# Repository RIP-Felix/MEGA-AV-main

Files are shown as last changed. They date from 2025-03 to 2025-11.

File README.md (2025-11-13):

# MegaAV
Sega Genesis audio and video bypass, incorporating an entirely new audio circuit design that restores mono audio, along with native composite and S-video generation.

Attribution: Credit where Credit's due

Timeline of events:
ACE9921 & Villahed94 developed the original Mega Amp 1.0. Inception for a mod board that combines the Mega Amp with an RGB video amplifier was Bob from RetroRGB's idea. Rene from db Electronics designed the first build. Tienfeng designed the second with a modified version of the then new Mega Amp 2.0, on which Jose Cruz helped with testing. That became the Triple Bypass v2.

Zaxour forked the 3BPv2 to support Composite restore with the 3BPV2+ and is continuing development of a Quadruple Bypass that will support S-video.

For most of the 6 years between the Mega Amp 2.0 and 3.0, Ace was pretty much developing alone. Villahed94, eep386, and ACE9921 were throwing ideas around, but nobody except Ace was doing anything. I want to make it clear that the Mega Amp 3 is it's own standalone thing still in development and that the Mega Audio is NOT to be confused with it. Ace is not associated with the MegaAV.

While they may use similar circuit topology, their goals are different, and they must not be used interchangeably

RIP-Felix incepted the idea of restoring Mono Audio for RF compatibility. RGBeter incepted the idea of recreating Composite video using a modern encoder, taking the opportunity to fix the luma trap. At that point it was still a derivative work of the 3BPV2+. Villahed94 agreed to join the MegaAV team to finish and implement the Mega Audio for both inboard and MegaAV mod board installations. The three of us tested and refined finalized values, and implemented the designs together. Both RIP-Felix and RGBeter designed the MegaAV PCB. The only part of the circuit that has remained unchanged is the THS7374 RGB amplifier. 

So the Mega AV is actually 2 mods in one. The Mega Video developed by RIP-Felix, RGBeter, and Villahed94. Mega Audio was developed with help from Villahed94 and others along the way. Villahed94, RGBeter and RIP-Felix dialed in PSG and FM resistor values to dial in MD fourier. That said I (RIP-Felix) want to thank and credit everyone involved in these mods regardless of how much of their contributions made it into the current version of Mega AV. It's been a collective effort and everyone should be credited for the hard work they've put in! Massive thanks to all of you!
 
NOTEs:
- Fujitsu ASICs, 315-5708-01 and 315-5660-01 needed an additional pulldown resistor. Instead of bridging jumper C, solder a 200Ohm 1% or lower tolerance resistor to it. May apply to Model 1 VA7 through Model 2 VA1.8. The Suffix -01 indicates it's a Fujitsu Chip. This DOES NOT apply to chips LACKING the suffix "-01".
- Adds a ZIF connector for a future ribbon cable design to greatly simplify installation

(instructions pending, same as 3bp install except composite and mono must also be isolated from the din, and the subcarrier line must be routed to the MegaAV)
### When routing the subcarrier line, make sure it's a shielded coaxial cable or twisted pair to prevent jailbars

Instructions pending:
## Model 1 Installation Guides
[Model 1 - VA1-VA6]
[Model 1 - VA7]
## Model 2 Installation Guides
[Model 2 - VA0-1.8]
[Model 2 - VA2]
[Model 2 - VA2.3] (needed)
[Model 2 - VA3]
[Model 2 - VA4]

## Model 3 Installation Guides
[Model 3 - VA1] (needed)
[Model 3 - VA2] (needed)

## Sega CDX
[CDX]

## Other
[Other forms of Genesis]

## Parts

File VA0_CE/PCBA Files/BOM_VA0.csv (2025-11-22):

R15,R17,R74,R75,R76 | 75 | Resistor_SMD:R_0402_1005Metric | C4275
R60,R61 | 100 | Resistor_SMD:R_0402_1005Metric | C25076
R53,R54,R55 | 330 | Resistor_SMD:R_0402_1005Metric | C25104
R34 | 820 | Resistor_SMD:R_0402_1005Metric | C23253
C32,C33,C39,C53 | 0.1uF | Capacitor_SMD:C_0805_2012Metric | C28233
R69,R71,R73 | 1.2k | Resistor_SMD:R_0402_1005Metric | C22765
C41,C45 | 100u | Capacitor_Tantalum_SMD:CP_EIA-3528-15_AVX-H | C16133
L1 | 100uH | Inductor_SMD:L_0805_2012Metric | C68035
R40,R41,R46,R47,R48,R49,R62,R64 | 10k | Resistor_SMD:R_0402_1005Metric | C25744
C3,C4,C14,C15,C19,C20,C21,C22,C24,C25,C26,C27,C28,C29,C30,C31,C34,C37,C51,C52,C54,C55 | 10uF | Capacitor_SMD:C_0805_2012Metric | C15850
C50 | 12p | Capacitor_SMD:C_0402_1005Metric | C1547
R30 | 15k | Resistor_SMD:R_0402_1005Metric | C25756
R70 | 1k | Resistor_SMD:R_0402_1005Metric | C11702
D2 | 1N4148W | Diode_SMD:D_SOD-323 | C2128
R21,R23,R36,R67,R68 | 2.2k | Resistor_SMD:R_0402_1005Metric | C25879
U2 | 2.5v linear Regulator | Package_TO_SOT_SMD:TSOT-23-5 | C22466441
R35 | 20k | Resistor_SMD:R_0402_1005Metric | C25765
C46,C47,C48,C56 | 220uF | Capacitor_Tantalum_SMD:CP_EIA-3528-15_AVX-H | C122649
R22,R24,R25 | 22k | Resistor_SMD:R_0402_1005Metric | C25768
R33 | 3.6k | Resistor_SMD:R_0402_1005Metric | C22980
R26,R29 | 36k | Resistor_SMD:R_0402_1005Metric | C23147
R52,R57,R58,R66 | 4.7k | Resistor_SMD:R_0402_1005Metric | C25900
R4,R5,R7,R8,R31,R32,R59,R72 | 47k | Resistor_SMD:R_0402_1005Metric | C25792
C1,C9,C11,C12,C13 | 47p | Capacitor_SMD:C_0402_1005Metric | C1567
C42,C43,C44 | 47u | Capacitor_SMD:C_1206_3216Metric | C96123
R37,R38,R56 | 5.6k | Resistor_SMD:R_0402_1005Metric | C23189
C35,C36 | 5.6nF | Capacitor_SMD:C_0402_1005Metric | C2976066
R27,R28,R65,R79 | 51k | Resistor_SMD:R_0402_1005Metric | C25794
C38 | 5p | Capacitor_SMD:C_0805_2012Metric | C309040
R39,R42 | 7.5k | Resistor_SMD:R_0402_1005Metric | C23234
C49 | 7p | Capacitor_SMD:C_0402_1005Metric | C5448838
R45 | 82k | Resistor_SMD:R_0402_1005Metric | C23254
Designator | Comment | Footprint | JLCPCB Part #
Z1 | Conn_01x33_Pin | Connector_FFC-FPC:Molex_502244-3330_1x33-1MP_P0.5mm_Horizontal
U6 | TS922 | Package_SO:SO-8_3.9x4.9mm_P1.27mm | C93687
U3 | TS924 | Package_SO:SO-14_3.9x8.65mm_P1.27mm | C1235674
U7 | TS924 | Package_SO:SO-14_3.9x8.65mm_P1.27mm | C1235674

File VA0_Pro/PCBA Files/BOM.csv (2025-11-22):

Designator | Comment | Footprint | LCSC Part #
R15,R17,R36,R37,R38,R43,R44,R45,R56,R57,R58 | 75 | Resistor_SMD:R_0603_1608Metric | C4275
R60,R61,R66,R67 | 100 | Resistor_SMD:R_0402_1005Metric | C25076
R53,R54,R55 | 330 | Resistor_SMD:R_0402_1005Metric | C25104
R69,R70,R71 | 374 | Resistor_SMD:R_0402_1005Metric | C270604
R68 | 620 | Resistor_SMD:R_0402_1005Metric | C4961
R34 | 820 | Resistor_SMD:R_0603_1608Metric | C23253
C23 | 0.01u | Capacitor_SMD:C_0402_1005Metric | C15195
C2,C8,C28,C30,C31,C32,C33,C34,C37,C39 | 100n | Capacitor_SMD:C_0402_1005Metric | C28233
C16,C17,C18 | 0.1u | Capacitor_SMD:C_0402_1005Metric | C1525
L1 | 100uH | Inductor_SMD:L_0805_2012Metric | C68035
R2,R3,R20,R40,R41,R46,R47,R48,R49,R62,R64 | 10k | Resistor_SMD:R_0402_1005Metric | C25744
C1,C3,C4,C10,C14,C15,C19,C20,C21,C22,C24,C25,C26,C27,C29,C38,C54,C55 | 10u | Capacitor_SMD:C_0805_2012Metric | C15850
C50 | 12p | Capacitor_SMD:C_0402_1005Metric | C1547
R30 | 15k | Resistor_SMD:R_0402_1005Metric | C25756
R16,R18,R19 | 1k | Resistor_SMD:R_0402_1005Metric | C11702
C6 | 1n | Capacitor_SMD:C_0402_1005Metric | C1523
D1,D2 | 1N4148W | Diode_SMD:D_SOD-323 | C2128
R6,R21,R23 | 2.2k | Resistor_SMD:R_0402_1005Metric | C25879
C41,C45,C46,C47,C48,C56 | 220u | Capacitor_Tantalum_SMD:CP_EIA-3528-15_AVX-H | C122649
R22,R24,R25 | 22k | Resistor_SMD:R_0402_1005Metric | C25768
C5,C7 | 22n | Capacitor_SMD:C_0402_1005Metric | C1532
R33 | 3.6k | Resistor_SMD:R_0603_1608Metric | C22980
R26,R29 | 36k | Resistor_SMD:R_0603_1608Metric | C23147
R1,R52 | 4.7k | Resistor_SMD:R_0402_1005Metric | C25900
R4,R5,R7,R8,R31,R32,R59,R72 | 47k | Resistor_SMD:R_0402_1005Metric | C25792
C9,C11,C12,C13 | 47p | Capacitor_SMD:C_0402_1005Metric | C1567
C42,C43,C44 | 47u | Capacitor_SMD:C_1206_3216Metric | C96123
R9,R10,R11,R12,R13,R14,R35 | 5.6k | Resistor_SMD:R_0603_1608Metric | C23189
R27,R28,R63,R65 | 51k | Resistor_SMD:R_0402_1005Metric | C25794
C35,C36 | 5600p | Capacitor_SMD:C_0402_1005Metric | C2976066
R39,R42 | 7.5k | Resistor_SMD:R_0603_1608Metric | C23234
U2 | 74HCT123 | Package_SO:TSSOP-16_4.4x5mm_P0.65mm | C191980
C49 | 7p | Capacitor_SMD:C_0402_1005Metric | C5448838
U8 | AD723 | Package_SO:TSSOP-28_6.1x9.7mm_P0.65mm
U1 | CD4070 | Package_SO:TSSOP-14_4.4x5mm_P0.65mm | C2865674
Z1 | Conn_01x33_Pin | Connector_FFC-FPC:Molex_502244-3330_1x33-1MP_P0.5mm_Horizontal
U5 | ICS501 | Package_SO:SOIC-8_3.9x4.9mm_P1.27mm
CN1 | MD-90SM_MD2 | MyLibrary:MD90SM-MD2
U9 | 2.5v linear Regulator | Package_TO_SOT_SMD:TSOT-23-5 | C22466441
U4 | THS7374 | Package_SO:TSSOP-14_4.4x5mm_P0.65mm
U6 | TS922 | Package_SO:TSSOP-8_4.4x3mm_P0.65mm | C93687
U3,U7 | TS924 | Package_SO:TSSOP-14_4.4x5mm_P0.65mm

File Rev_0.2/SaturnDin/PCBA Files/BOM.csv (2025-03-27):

Designator | Comment | Footprint
~ | 5V1,32XPD1,32XPD2,B_IN1,CDPD1,CDPD2,CLK_IN1,GND1,G_IN1,LPF1,M1PU1,PAL1,R_IN1,S_IN1 | Connector_Wire:SolderWirePad_1x01_SMD_1x2mm,Jumper:SolderJumper-2_P1.3mm_Open_RoundedPad1.0x1.5mm
SMD_Conn_01x01 | 32X_L1,32X_R1,CD_L1,CD_R1,FM_L1,FM_R1,P1 | Connector_Wire:SolderWirePad_1x01_SMD_1x2mm
0.01u | C1 | Capacitor_SMD:C_0402_1005Metric
10u | C2,C3,C8,C9,C14,C15,C16,C17,C19,C20,C21,C22,C23,C32,C45,C48 | Capacitor_SMD:C_0805_2012Metric
27p | C4,C5,C6,C7 | Capacitor_SMD:C_0402_1005Metric
0.1u | C10,C11,C12,C13,C18,C27,C28,C29,C33,C46,C47 | Capacitor_SMD:C_0402_1005Metric
220u | C24,C25,C26,C36,C38,C41,C42,C43,C44 | Capacitor_Tantalum_SMD:CP_EIA-3528-15_AVX-H
5600p | C30,C31 | Capacitor_SMD:C_0402_1005Metric
47u | C34,C35 | Capacitor_Tantalum_SMD:CP_EIA-3528-15_AVX-H
9p | C39 | Capacitor_SMD:C_0402_1005Metric
18p | C40 | Capacitor_SMD:C_0402_1005Metric
MD-90SM_MD2 | CN1 | MyLibrary:MD10SM-SS
1N4148W | D1 | Diode_SMD:D_SOD-123
SolderJumper_2_Open | FM_L1-1,FM_L1-2,FM_L2-1,FM_L2-2,FM_L3-1,FM_L3-2,FM_R1-1,FM_R1-2,FM_R2-1,FM_R2-2,FM_R3-1,FM_R3-2 | Jumper:SolderJumper-2_P1.3mm_Open_RoundedPad1.0x1.5mm
SolderJumper_3_Open | PSGPD1 | Jumper:SolderJumper-3_P1.3mm_Open_RoundedPad1.0x1.5mm
100k | R1,R2,R3,R4,R20,R23,R48,R49 | Resistor_SMD:R_0402_1005Metric
2.2k | R5,R8 | Resistor_SMD:R_0402_1005Metric
5.62k | R6,R9,R10,R11,R12,R13,R16,R32,R42 | Resistor_SMD:R_0402_1005Metric
750 | R7 | Resistor_SMD:R_0402_1005Metric
1k | R14,R15,R17 | Resistor_SMD:R_0402_1005Metric
75 | R18,R25,R33,R34,R35,R36,R37,R43,R44,R46,R52,R54,R56,R57,R58,R59 | Resistor_SMD:R_0402_1005Metric
10k | R19,R22,R61,R62 | Resistor_SMD:R_0402_1005Metric
130k | R21,R24 | Resistor_SMD:R_0402_1005Metric
210k | R26,R27,R28,R29 | Resistor_SMD:R_0402_1005Metric
300k | R30,R31 | Resistor_SMD:R_0402_1005Metric
21k | R38,R41 | Resistor_SMD:R_0402_1005Metric
30k | R39,R40,R45,R47 | Resistor_SMD:R_0402_1005Metric
330 | R50,R51 | Resistor_SMD:R_0402_1005Metric
51k | R53 | Resistor_SMD:R_0402_1005Metric
470 | R60 | Resistor_SMD:R_0402_1005Metric
ICS501 | U1 | Package_SO:SOIC-8_3.9x4.9mm_P1.27mm
MC33204 | U2,U4 | Package_SO:TSSOP-14_4.4x5mm_P0.65mm
THS7374 | U3 | Package_SO:TSSOP-14_4.4x5mm_P0.65mm
AD725 | U5 | Package_SO:SOIC-16W_7.5x10.3mm_P1.27mm
Conn_01x33_Pin | Z1 | Connector_FFC-FPC:Molex_502244-3330_1x33-1MP_P0.5mm_Horizontal

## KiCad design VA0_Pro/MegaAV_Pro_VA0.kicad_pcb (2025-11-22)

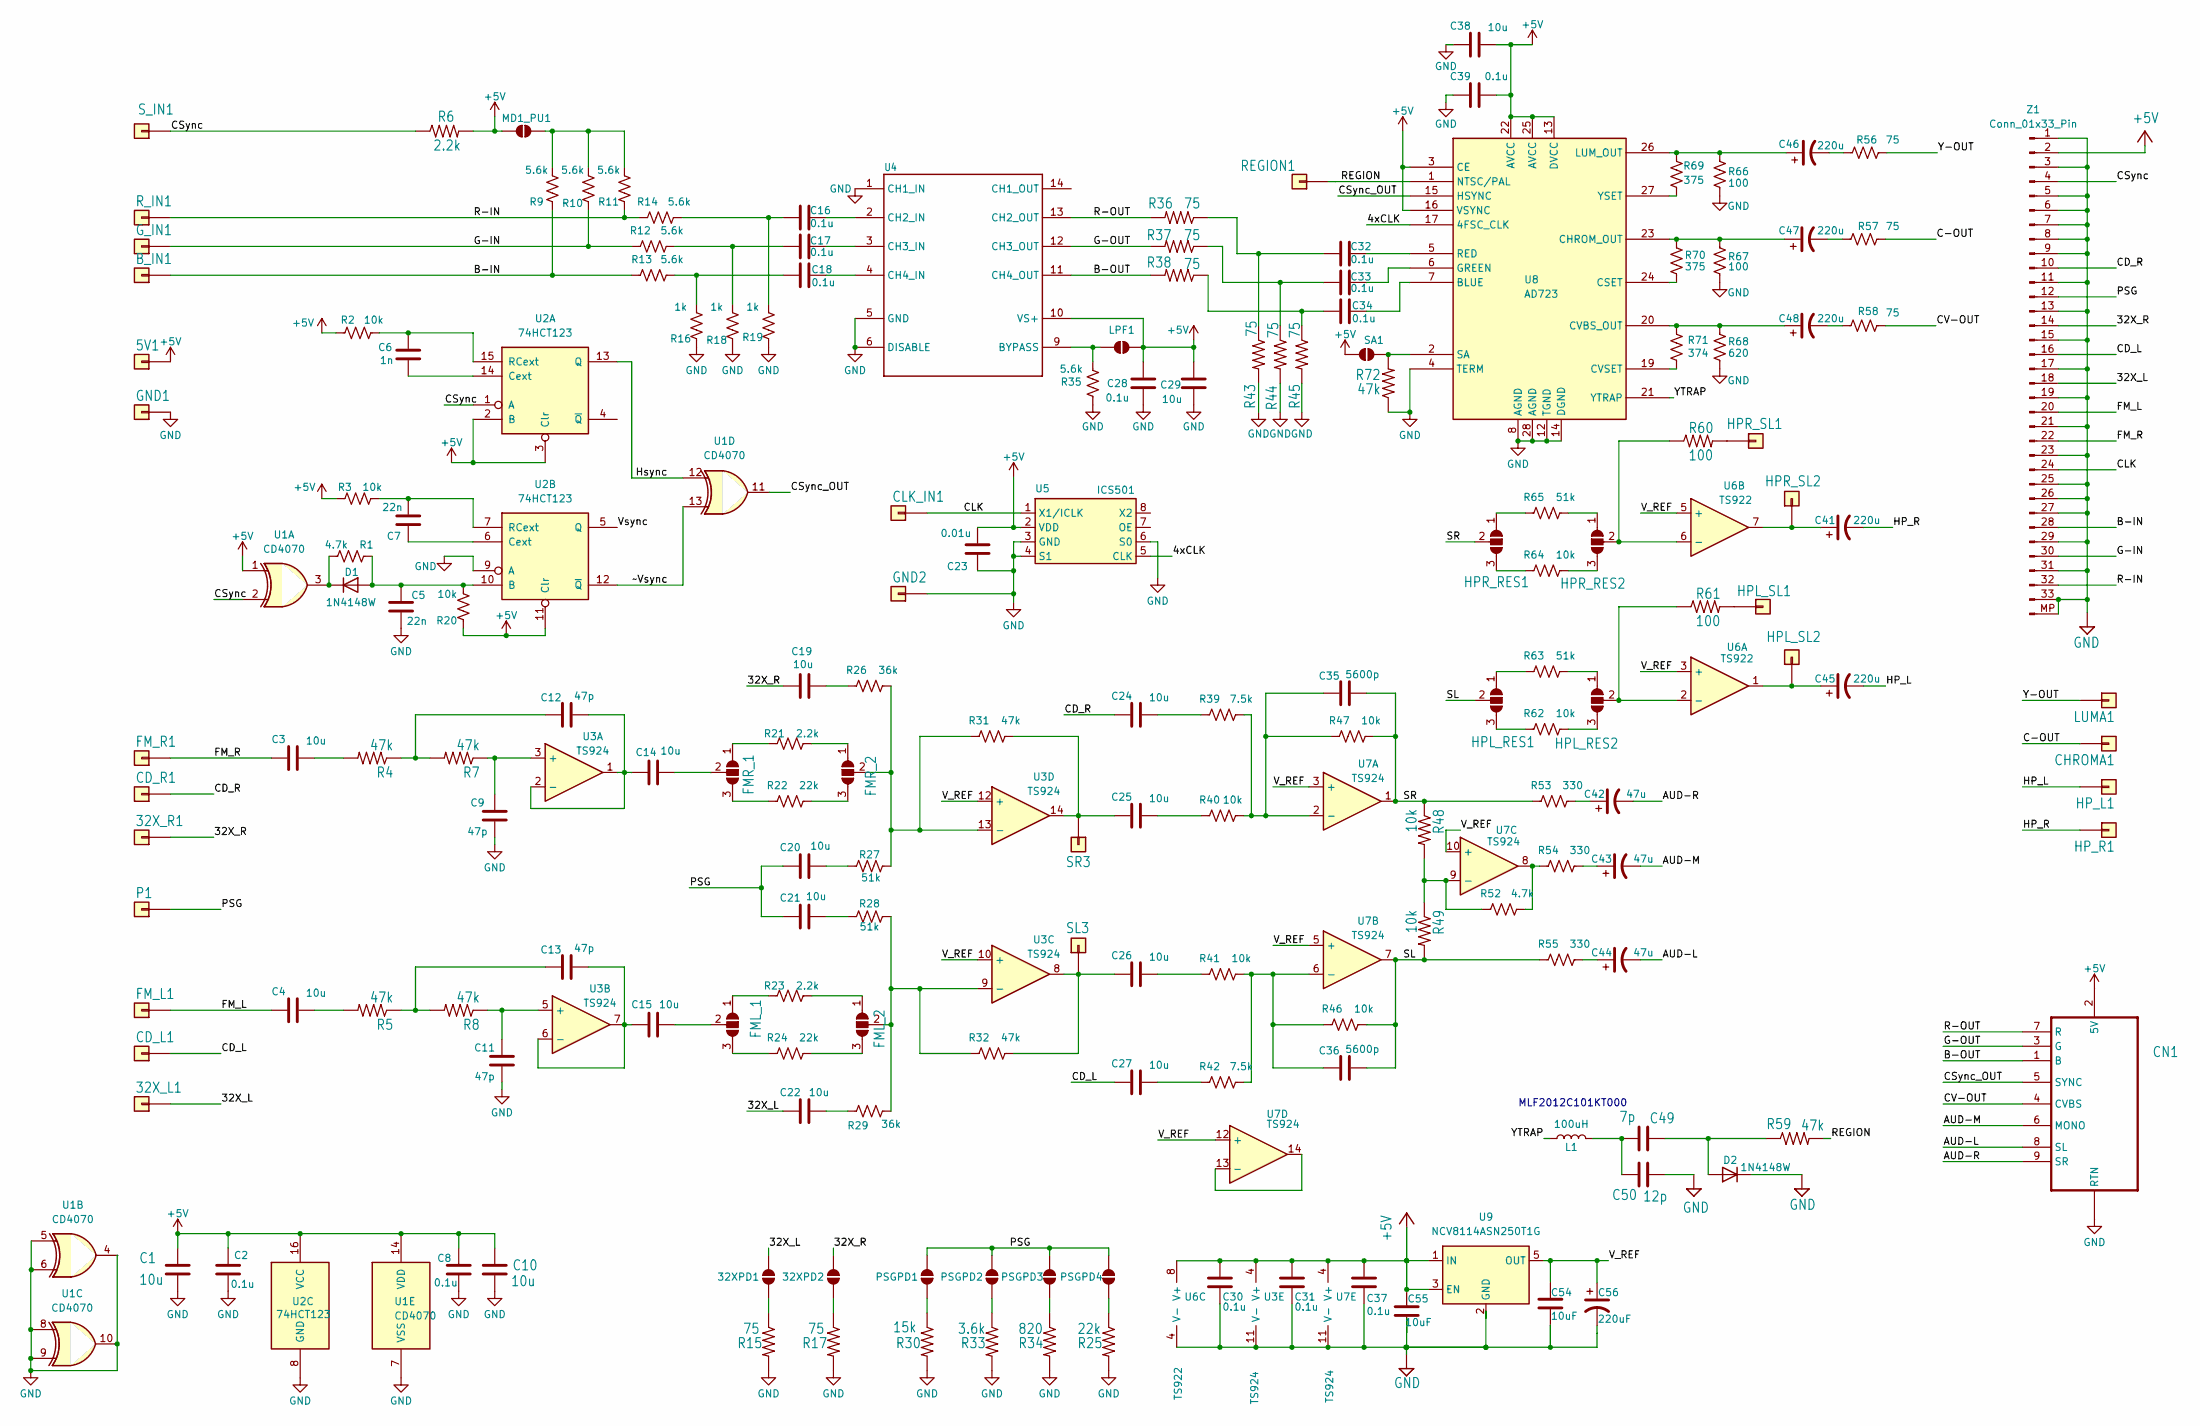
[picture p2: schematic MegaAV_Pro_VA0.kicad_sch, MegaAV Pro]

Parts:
5V1: SolderWirePad_1x01_SMD_1x2mm
32XPD1, 32XPD2: SolderJumper-2_P1.3mm_Open_RoundedPad1.0x1.5mm
32X_L1, 32X_R1: SMD_Conn_01x01; SolderWirePad_1x01_SMD_1x2mm
B_IN1: SolderWirePad_1x01_SMD_1x2mm
C1, C3, C4, C10, C14, C15, C19, C20, C21, C22, C24, C25, C26, C27, C29, C38: 10u; C_0805_2012Metric
C2, C8, C16, C17, C18, C30, C31, C32, C33, C34, C37, C39: 0.1u; C_0402_1005Metric
C5, C7: 22n; C_0402_1005Metric
C6: 1n; C_0402_1005Metric
C9, C11, C12, C13: 47p; C_0402_1005Metric
C23: 0.01u; C_0402_1005Metric
C28: 0.1u; C_0805_2012Metric
C35, C36: 5600p; C_0402_1005Metric
C41, C45, C46, C47, C48: 220u; CP_EIA-3528-15_AVX-H
C42, C43, C44: 47u; C_1206_3216Metric
C49: 7p; C_0402_1005Metric
C50: 12p; C_0402_1005Metric
C54: 10uF; C_0805_2012Metric; MPN VJ0805A330FXJPW1BC; LCSC Part # C520060
C55: 10uF; C_0805_2012Metric
C56: 220uF; CP_EIA-3528-15_AVX-H
CD_L1: SMD_Conn_01x01; SolderWirePad_1x01_SMD_1x2mm
CD_R1: SMD_Conn_01x01; SolderWirePad_1x01_SMD_1x2mm
CHROMA1: SMD_Conn_01x01; SolderWirePad_1x01_SMD_1x2mm
CLK_IN1: SolderWirePad_1x01_SMD_1x2mm
CN1: MD-90SM_MD2; MD90SM-MD2
D1, D2: 1N4148W; D_SOD-323F
FML_1, FML_2: SolderJumper_3_Open; SolderJumper-3_P1.3mm_Open_RoundedPad1.0x1.5mm
FMR_1, FMR_2: SolderJumper_3_Open; SolderJumper-3_P1.3mm_Open_RoundedPad1.0x1.5mm
FM_L1: SMD_Conn_01x01; SolderWirePad_1x01_SMD_1x2mm
FM_R1: SMD_Conn_01x01; SolderWirePad_1x01_SMD_1x2mm
GND1: SolderWirePad_1x01_SMD_1x2mm
GND2: SMD_Conn_01x01; SolderWirePad_1x01_SMD_1x2mm
G_IN1: SolderWirePad_1x01_SMD_1x2mm
HPL_RES1, HPL_RES2: SolderJumper_3_Open; SolderJumper-3_P1.3mm_Open_RoundedPad1.0x1.5mm
HPL_SL1, HPL_SL2: SMD_Conn_01x01; SolderWirePad_1x01_SMD_1x2mm
HPR_RES1, HPR_RES2: SolderJumper_3_Open; SolderJumper-3_P1.3mm_Open_RoundedPad1.0x1.5mm
HPR_SL1, HPR_SL2: SMD_Conn_01x01; SolderWirePad_1x01_SMD_1x2mm
HP_L1: SMD_Conn_01x01; SolderWirePad_1x01_SMD_1x2mm
HP_R1: SMD_Conn_01x01; SolderWirePad_1x01_SMD_1x2mm
L1: 100uH; L_0805_2012Metric
LPF1: SolderJumper-2_P1.3mm_Open_RoundedPad1.0x1.5mm
LUMA1: SMD_Conn_01x01; SolderWirePad_1x01_SMD_1x2mm
MD1_PU1: SolderJumper-2_P1.3mm_Open_RoundedPad1.0x1.5mm
P1: SMD_Conn_01x01; SolderWirePad_1x01_SMD_1x2mm
PSGPD1, PSGPD2, PSGPD3, PSGPD4: SolderJumper-2_P1.3mm_Open_RoundedPad1.0x1.5mm
R1, R52: 4.7k; R_0402_1005Metric
R2, R3, R20, R40, R41, R46, R47, R48, R49, R62, R64: 10k; R_0402_1005Metric
R4, R5, R7, R8, R31, R32, R59, R72: 47k; R_0402_1005Metric
R6, R21, R23: 2.2k; R_0402_1005Metric
R9, R10, R11, R12, R13, R14, R35: 5.6k; R_0603_1608Metric
R15, R17, R36, R37, R38, R43, R44, R45, R56, R57, R58: 75; R_0603_1608Metric
R16, R18, R19: 1k; R_0402_1005Metric
R22, R24, R25: 22k; R_0402_1005Metric
R26, R29: 36k; R_0603_1608Metric
R27, R28, R63, R65: 51k; R_0402_1005Metric
R30: 15k; R_0402_1005Metric
R33: 3.6k; R_0603_1608Metric
R34: 820; R_0603_1608Metric
R39, R42: 7.5k; R_0603_1608Metric
R53, R54, R55: 330; R_0402_1005Metric
R60, R61, R66, R67: 100; R_0402_1005Metric
R68: 620; R_0402_1005Metric
R69, R70: 375; R_0402_1005Metric
R71: 374; R_0402_1005Metric
REGION1: SolderWirePad_1x01_SMD_1x2mm
R_IN1: SolderWirePad_1x01_SMD_1x2mm
SA1: SolderJumper-2_P1.3mm_Open_RoundedPad1.0x1.5mm
SL3: SMD_Conn_01x01; SolderWirePad_1x01_SMD_1x2mm
SR3: SMD_Conn_01x01; SolderWirePad_1x01_SMD_1x2mm
S_IN1: SolderWirePad_1x01_SMD_1x2mm
U1: CD4070; TSSOP-14_4.4x5mm_P0.65mm
U2: 74HCT123; TSSOP-16_4.4x5mm_P0.65mm
U3, U7: TS924; TSSOP-14_4.4x5mm_P0.65mm
U4: THS7374; TSSOP-14_4.4x5mm_P0.65mm
U5: ICS501; SOIC-8_3.9x4.9mm_P1.27mm
U6: TS922; SO-8_3.9x4.9mm_P1.27mm
U8: AD723; TSSOP-28_6.1x9.7mm_P0.65mm
U9: NCV8114ASN250T1G; TSOT-23-5
Z1: Conn_01x33_Pin; Molex_502244-3330_1x33-1MP_P0.5mm_Horizontal

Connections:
+5V: 5V1.1, C1.1, C2.1, C8.1, C10.1, C23.2, C28.1, C29.1, C30.1, C31.1, C37.1, C38.2, C39.2, C55.1, CN1.2 (5V), LPF1.2 (B), MD1_PU1.2 (B), R2.2, R3.1, R6.2, R20.1, SA1.1 (A), U1.1, U1.14 (VDD), U2.2 (B), U2.3 (Clr), U2.11 (Clr), U2.16 (VCC), U3.4 (V+), U4.10 (VS+), U5.2 (VDD), U6.8 (V+), U7.4 (V+), U8.3 (CE), U8.13 (DVCC), U8.16 (VSYNC), U8.22 (AVCC), U8.25 (AVCC), U9.1 (IN), U9.3 (EN), Z1.2
/4xCLK: U5.5 (CLK), U8.17 (4FSC_CLK)
/32X_L: 32XPD1.2 (B), 32X_L1.1, C22.1, Z1.18
/32X_R: 32XPD2.2 (B), 32X_R1.1, C19.1, Z1.14
/AUD-L: C44.2, CN1.8 (SL)
/AUD-M: C43.2, CN1.6 (MONO)
/AUD-R: C42.2, CN1.9 (SR)
/B-IN: B_IN1.1, R9.1, R13.1, Z1.28
/B-OUT: CN1.1 (B), R38.2, U4.11 (CH4_OUT)
/C-OUT: CHROMA1.1, R57.2
/CD_L: C27.1, CD_L1.1, Z1.16
/CD_R: C24.1, CD_R1.1, Z1.10
/CLK: CLK_IN1.1, U5.1 (X1/ICLK), Z1.24
/CSync: R6.1, S_IN1.1, U1.2, U2.1 (A), Z1.4
/CSync_OUT: CN1.5 (SYNC), U1.11, U8.15 (HSYNC)
/CV-OUT: CN1.4 (CVBS), R58.2
/FM_L: C4.1, FM_L1.1, Z1.20
/FM_R: C3.1, FM_R1.1, Z1.22
/G-IN: G_IN1.1, R10.1, R12.1, Z1.30
/G-OUT: CN1.3 (G), R37.2, U4.12 (CH3_OUT)
/HP_L: C45.2, HP_L1.1
/HP_R: C41.2, HP_R1.1
/Hsync: U1.12, U2.13 (Q)
/PSG: C20.1, C21.1, P1.1, PSGPD1.2 (B), PSGPD2.2 (B), PSGPD3.2 (B), PSGPD4.2 (B), Z1.12
/R-IN: R11.1, R14.1, R_IN1.1, Z1.32
/R-OUT: CN1.7 (R), R36.2, U4.13 (CH2_OUT)
/REGION: R59.2, REGION1.1, U8.1 (NTSC/PAL); also elsewhere on the board
/SL: C36.2, HPL_RES1.2 (C), R46.2, R49.2, R55.1, U7.7
/SR: C35.2, HPR_RES1.2 (C), R47.2, R48.1, R53.1, U7.1
/V_REF: C54.1, C56.1, U3.10 (+), U3.12 (+), U6.3 (+), U6.5 (+), U7.3 (+), U7.5 (+), U7.10 (+), U7.12 (+), U9.5 (OUT)
/Vsync: U2.5 (Q)
/Y-OUT: LUMA1.1, R56.2
/YTRAP: L1.1, U8.21 (YTRAP)
/~Vsync: U1.13, U2.12 (~Q)
GND: C1.2, C2.2, C5.1, C8.2, C9.2, C10.2, C11.2, C23.1, C28.2, C29.2, C30.2, C31.2, C37.2, C38.1, C39.1, C50.2, C54.2, C55.2, C56.2, CN1.S1 (RTN), CN1.S2 (RTN), CN1.S3 (RTN), D2.1 (K), GND1.1, GND2.1, R15.2, R16.1, R17.2, R18.1, R19.1, R25.2, R30.2, R33.2, R34.2, R35.1, R43.2, R44.2, R45.2, R66.2, R67.2, R68.2, R72.1, U1.4, U1.5, U1.6, U1.7 (VSS), U1.8, U1.9, U1.10, U2.8 (GND), U2.9 (A), U3.11 (V-), U4.1 (CH1_IN), U4.5 (GND), U4.6 (DISABLE), U5.3 (GND), U5.4 (S1), U5.6 (S0), U6.4 (V-), U7.11 (V-), U8.4 (TERM), U8.8 (AGND), U8.12 (TGND), U8.14 (DGND), U8.28 (AGND), U9.2 (GND), Z1.1, Z1.3, Z1.5, Z1.6, Z1.7, Z1.8, Z1.9, Z1.11, Z1.13, Z1.15, Z1.17, Z1.19, Z1.21, Z1.23, Z1.25, Z1.26, Z1.27, Z1.29, Z1.31, Z1.33, Z1.MP
unnamed: 32XPD1.1 (A), R15.1
unnamed: 32XPD2.1 (A), R17.1
unnamed: C3.2, R4.2
unnamed: C4.2, R5.2
unnamed: C12.1, R4.1, R7.2
unnamed: C13.1, R5.1, R8.2
unnamed: C16.1, R14.2, R19.2
unnamed: C17.1, R12.2, R18.2
unnamed: C18.1, R13.2, R16.2
unnamed: C19.2, R26.1
unnamed: C20.2, R27.1
unnamed: C21.2, R28.1
unnamed: C22.2, R29.1
unnamed: C24.2, R39.1
unnamed: C25.2, R40.1
unnamed: C26.2, R41.1
unnamed: C27.2, R42.1
unnamed: C32.1, R36.1, R43.1
unnamed: C33.1, R37.1, R44.1
unnamed: C34.1, R38.1, R45.1
unnamed: C42.1, R53.2
unnamed: C43.1, R54.2
unnamed: C44.1, R55.2
unnamed: C46.2, R56.1
unnamed: C47.2, R57.1
unnamed: C48.2, R58.1
unnamed: C49.2, C50.1, L1.2
unnamed: C5.2, D1.2 (A), R1.1, R20.2, U2.10 (B)
unnamed: D1.1 (K), R1.2, U1.3
unnamed: C49.1, D2.2 (A), R59.1
unnamed: FML_1.1 (A), R23.1
unnamed: FML_1.3 (B), R24.1
unnamed: C15.2, FML_1.2 (C)
unnamed: FML_2.1 (A), R23.2
unnamed: FML_2.3 (B), R24.2
unnamed: FML_2.2 (C), R28.2, R29.2, R32.1, U3.9 (-)
unnamed: FMR_1.1 (A), R21.1
unnamed: FMR_1.3 (B), R22.1
unnamed: C14.2, FMR_1.2 (C)
unnamed: FMR_2.1 (A), R21.2
unnamed: FMR_2.3 (B), R22.2
unnamed: FMR_2.2 (C), R26.2, R27.2, R31.1, U3.13 (-)
unnamed: HPL_RES1.1 (A), R63.1
unnamed: HPL_RES1.3 (B), R62.1
unnamed: HPL_RES2.1 (A), R63.2
unnamed: HPL_RES2.3 (B), R62.2
unnamed: HPL_RES2.2 (C), R61.1, U6.2 (-)
unnamed: HPL_SL1.1, R61.2
unnamed: C45.1, HPL_SL2.1, U6.1
unnamed: HPR_RES1.1 (A), R65.1
unnamed: HPR_RES1.3 (B), R64.1
unnamed: HPR_RES2.1 (A), R65.2
unnamed: HPR_RES2.3 (B), R64.2
unnamed: HPR_RES2.2 (C), R60.1, U6.6 (-)
unnamed: HPR_SL1.1, R60.2
unnamed: C41.1, HPR_SL2.1, U6.7
unnamed: LPF1.1 (A), R35.2, U4.9 (BYPASS)
unnamed: MD1_PU1.1 (A), R9.2, R10.2, R11.2
unnamed: PSGPD1.1 (A), R30.1
unnamed: PSGPD2.1 (A), R33.1
unnamed: PSGPD3.1 (A), R34.1
unnamed: PSGPD4.1 (A), R25.1
unnamed: R52.2, R54.1, U7.8
unnamed: R72.2, SA1.2 (B), U8.2 (SA)
unnamed: C26.1, R32.2, SL3.1, U3.8
unnamed: C25.1, R31.2, SR3.1, U3.14
unnamed: C6.1, U2.14 (Cext)
unnamed: C6.2, R2.1, U2.15 (RCext)
unnamed: C7.1, U2.6 (Cext)
unnamed: C7.2, R3.2, U2.7 (RCext)
unnamed: C9.1, R7.1, U3.3 (+)
unnamed: C12.2, C14.1, U3.1, U3.2 (-)
unnamed: C11.1, R8.1, U3.5 (+)
unnamed: C13.2, C15.1, U3.6 (-), U3.7
unnamed: C16.2, U4.2 (CH2_IN)
unnamed: C17.2, U4.3 (CH3_IN)
unnamed: C18.2, U4.4 (CH4_IN)
unnamed: C35.1, R39.2, R40.2, R47.1, U7.2 (-)
unnamed: C36.1, R41.2, R42.2, R46.1, U7.6 (-)
unnamed: R48.2, R49.1, R52.1, U7.9 (-)
unnamed: U7.13 (-), U7.14
unnamed: C34.2, U8.7 (BLUE)
unnamed: C47.1, R67.1, R70.2, U8.23 (CHROM_OUT)
unnamed: R70.1, U8.24 (CSET)
unnamed: C48.1, R68.1, R71.2, U8.20 (CVBS_OUT)
unnamed: R71.1, U8.19 (CVSET)
unnamed: C33.2, U8.6 (GREEN)
unnamed: C46.1, R66.1, R69.1, U8.26 (LUM_OUT)
unnamed: C32.2, U8.5 (RED)
unnamed: R69.2, U8.27 (YSET)

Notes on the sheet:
MLF2012C101KT000

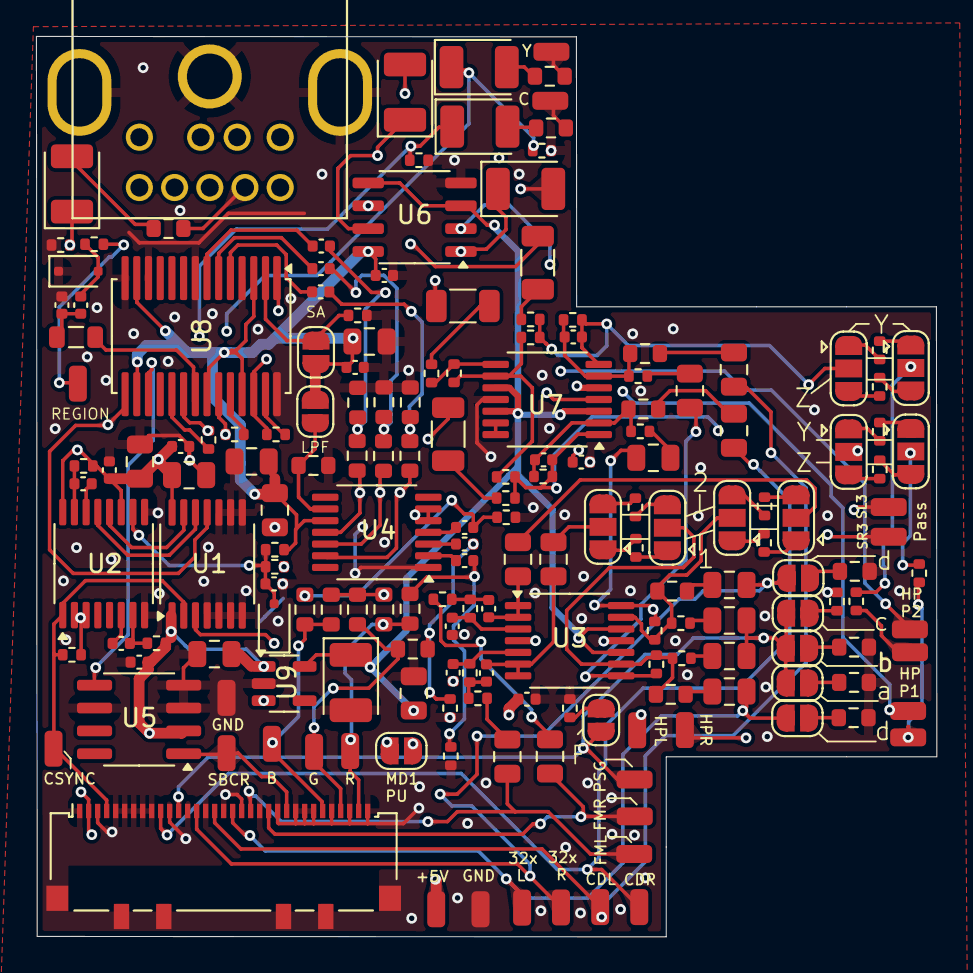
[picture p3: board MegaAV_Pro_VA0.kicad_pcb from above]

Board: 4 copper layers, 50.0 x 50.0 mm, 179 parts (0 on the bottom side), 124 nets.

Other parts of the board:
REGION: SolderWirePad_1x01_SMD_1x2mm

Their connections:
/REGION: REGION.1; also elsewhere on the board

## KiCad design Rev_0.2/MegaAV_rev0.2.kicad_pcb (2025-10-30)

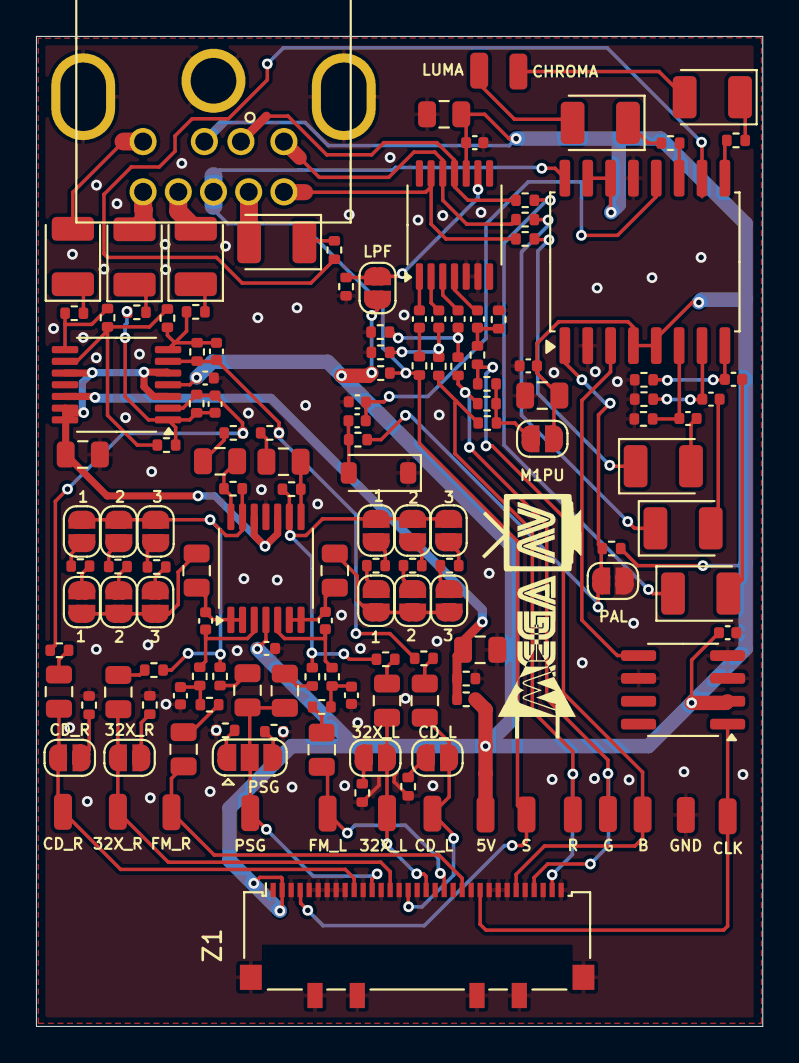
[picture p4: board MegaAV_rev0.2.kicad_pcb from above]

Board: 2 copper layers, 40.4 x 55.0 mm, 148 parts (0 on the bottom side), 103 nets.

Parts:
5V: SolderWirePad_1x01_SMD_1x2mm
32X_L, 32X_R: SMD_Conn_01x01; SolderWirePad_1x01_SMD_1x2mm
32X_L#2, 32X_R#2: SolderJumper-2_P1.3mm_Open_RoundedPad1.0x1.5mm
B: SolderWirePad_1x01_SMD_1x2mm
C1: 0.01u; C_0402_1005Metric
C2, C3, C8, C9, C14, C15, C16, C17, C19, C20, C21, C22, C23, C32, C42, C45: 10u; C_0805_2012Metric
C4, C5, C6, C7: 27p; C_0402_1005Metric
C10, C11, C12, C13, C18, C27, C28, C29, C33, C43, C44: 0.1u; C_0402_1005Metric
C24, C25, C26, C39, C40, C41: 220u; CP_EIA-3528-15_AVX-H
C30, C31: 5600p; C_0402_1005Metric
C34, C35, C36: 47u; CP_EIA-3528-15_AVX-H
C37: 9p; C_0402_1005Metric
C38: 18p; C_0402_1005Metric
CD_L: SMD_Conn_01x01; SolderWirePad_1x01_SMD_1x2mm
CD_L#2: SolderJumper-2_P1.3mm_Open_RoundedPad1.0x1.5mm
CD_R: SolderJumper-2_P1.3mm_Open_RoundedPad1.0x1.5mm
CD_R#2: SMD_Conn_01x01; SolderWirePad_1x01_SMD_1x2mm
CHROMA: SMD_Conn_01x01; SolderWirePad_1x01_SMD_1x2mm
CLK: SolderWirePad_1x01_SMD_1x2mm
CN1: MD-90SM_MD2; MD90SM-MD2
D1: 1N4148W; D_SOD-123
FM_L: SMD_Conn_01x01; SolderWirePad_1x01_SMD_1x2mm
FM_L1-1, FM_L1-2, FM_L2-1, FM_L2-2, FM_L3-1, FM_L3-2: SolderJumper_2_Open; SolderJumper-2_P1.3mm_Open_RoundedPad1.0x1.5mm
FM_R: SMD_Conn_01x01; SolderWirePad_1x01_SMD_1x2mm
FM_R1-1, FM_R1-2, FM_R2-1, FM_R2-2, FM_R3-1, FM_R3-2: SolderJumper_2_Open; SolderJumper-2_P1.3mm_Open_RoundedPad1.0x1.5mm
G: SolderWirePad_1x01_SMD_1x2mm
GND: SolderWirePad_1x01_SMD_1x2mm
LPF: SolderJumper-2_P1.3mm_Open_RoundedPad1.0x1.5mm
LUMA: SMD_Conn_01x01; SolderWirePad_1x01_SMD_1x2mm
M1PU: SolderJumper-2_P1.3mm_Open_RoundedPad1.0x1.5mm
PAL: SolderJumper-2_P1.3mm_Open_RoundedPad1.0x1.5mm
PSG: SMD_Conn_01x01; SolderWirePad_1x01_SMD_1x2mm
PSG#2: SolderJumper_3_Open; SolderJumper-3_P1.3mm_Open_RoundedPad1.0x1.5mm
R: SolderWirePad_1x01_SMD_1x2mm
R1, R2, R3, R4, R20, R23, R48, R49: 100k; R_0402_1005Metric
R5, R8: 2.2k; R_0402_1005Metric
R6, R9, R10, R11, R12, R13, R16, R32, R42: 5.62k; R_0402_1005Metric
R7: 750; R_0402_1005Metric
R14, R15, R17: 1k; R_0402_1005Metric
R18, R25, R33, R34, R35, R36, R37, R43, R44, R46, R54, R55, R56: 75; R_0402_1005Metric
R19, R22, R58, R59: 10k; R_0402_1005Metric
R21, R24: 130k; R_0402_1005Metric
R26, R27, R28, R29: 210k; R_0402_1005Metric
R30, R31: 300k; R_0402_1005Metric
R38, R41: 21k; R_0402_1005Metric
R39, R40, R45, R47: 30k; R_0402_1005Metric
R50, R51, R53: 330; R_0402_1005Metric
R52: 51k; R_0402_1005Metric
R57: 470; R_0402_1005Metric
S: SolderWirePad_1x01_SMD_1x2mm
U1: ICS501; SOIC-8_3.9x4.9mm_P1.27mm
U2, U4: MC33204; TSSOP-14_4.4x5mm_P0.65mm
U3: THS7374; TSSOP-14_4.4x5mm_P0.65mm
U5: AD725; SOIC-16W_7.5x10.3mm_P1.27mm
Z1: Conn_01x33_Pin; Molex_502244-3330_1x33-1MP_P0.5mm_Horizontal

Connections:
+5V: 5V.1, C1.2, C18.1, C23.1, C32.2, C33.2, C43.1, C44.1, CN1.2 (5V), LPF.2 (B), M1PU.2 (B), R5.2, R42.1, R58.2, U1.2 (VDD), U2.4 (V+), U3.10 (VS+), U4.4 (V+), U5.4 (AVCC), U5.5 (CE), U5.14 (DVCC), U5.15 (VSYNC), Z1.2
/2V5: C45.1, R58.1, R59.2, U4.12 (+)
/4xCLK: U1.5 (CLK), U5.3 (4FSC_CLK)
/32X_L: 32X_L.1, 32X_L#2.2 (B), C17.1, Z1.18
/32X_R: 32X_R.1, 32X_R#2.1 (A), C14.1, Z1.14
/AUD-L: C35.2, CN1.8 (SL)
/AUD-M: C36.2, CN1.6 (MONO)
/AUD-R: C34.2, CN1.9 (SR)
/B-IN: B.1, R6.1, R13.1, Z1.28
/B-OUT: CN1.1 (B), R36.1, U3.11 (CH4_OUT)
/C-OUT: C40.2, CHROMA.1
/CD_L: C22.1, CD_L.1, CD_L#2.2 (B), Z1.16
/CD_R: C19.1, CD_R.2 (B), CD_R#2.1, Z1.10
/CLK: CLK.1, U1.1 (X1/ICLK), Z1.24
/CSync: CN1.5 (SYNC), R5.1, R16.1, S.1, U5.16 (HSYNC), Z1.4
/CV-OUT: C41.2, CN1.4 (CVBS)
/FM_L: C3.1, FM_L.1, Z1.20
/FM_R: C2.1, FM_R.1, Z1.22
/G-IN: G.1, R9.1, R12.1, Z1.30
/G-OUT: CN1.3 (G), R35.1, U3.12 (CH3_OUT)
/PSG: C15.1, C16.1, PSG.1, PSG#2.2 (C), Z1.12
/R-IN: R.1, R10.1, R11.1, Z1.32
/R-OUT: CN1.7 (R), R34.1, U3.13 (CH2_OUT)
/STDSEL: PAL.1 (A), R42.2, R57.2, U5.1 (NTSC/PAL)
/V_REF: C42.1, U2.10 (+), U2.12 (+), U4.3 (+), U4.5 (+), U4.10 (+), U4.13 (-), U4.14
/Y-OUT: C39.2, LUMA.1
GND: C1.1, C4.2, C5.2, C18.2, C23.2, C32.1, C33.1, C38.2, C42.2, C43.2, C44.2, C45.2, CN1.S1 (RTN), CN1.S2 (RTN), CN1.S3 (RTN), D1.1 (K), GND.1, PAL.2 (B), R7.2, R8.2, R14.1, R15.1, R17.1, R18.2, R25.1, R32.1, R33.2, R37.2, R43.1, R44.1, R46.1, R59.1, U1.3 (GND), U1.4 (S1), U1.6 (S0), U2.11 (V-), U3.5 (GND), U3.6 (DISABLE), U4.11 (V-), U5.2 (AGND), U5.13 (DGND), Z1.1, Z1.3, Z1.5, Z1.6, Z1.7, Z1.8, Z1.9, Z1.11, Z1.13, Z1.15, Z1.17, Z1.19, Z1.21, Z1.23, Z1.25, Z1.26, Z1.27, Z1.29, Z1.31, Z1.33, Z1.MP
unnamed: 32X_L#2.1 (A), R18.1
unnamed: 32X_R#2.2 (B), R25.2
unnamed: C2.2, R1.2
unnamed: C3.2, R2.2
unnamed: C4.1, R1.1, R3.2
unnamed: C5.1, R2.1, R4.2
unnamed: C10.1, R16.2
unnamed: C11.1, R11.2, R17.2
unnamed: C12.1, R12.2, R15.2
unnamed: C13.1, R13.2, R14.2
unnamed: C14.2, R26.1
unnamed: C15.2, R27.1
unnamed: C16.2, R28.1
unnamed: C17.2, R29.1
unnamed: C19.2, R38.1
unnamed: C20.1, R30.2, U2.14
unnamed: C20.2, R39.1
unnamed: C21.1, R31.2, U2.8
unnamed: C21.2, R40.1
unnamed: C22.2, R41.1
unnamed: C24.1, R34.2
unnamed: C24.2, C27.1
unnamed: C25.1, R35.2
unnamed: C25.2, C28.1
unnamed: C26.1, R36.2
unnamed: C26.2, C29.1
unnamed: C30.2, R47.2, R48.1, R50.1, U4.1
unnamed: C31.2, R45.2, R49.2, R51.1, U4.7
unnamed: C34.1, R50.2
unnamed: C35.1, R51.2
unnamed: C36.1, R53.2
unnamed: C39.1, R54.2
unnamed: C40.1, R55.2
unnamed: C41.1, R56.2
unnamed: CD_L#2.1 (A), R33.1
unnamed: CD_R.1 (A), R37.1
unnamed: C37.1, D1.2 (A), R57.1
unnamed: C9.2, FM_L1-1.1 (A), FM_L2-1.1 (A), FM_L3-1.1 (A)
unnamed: FM_L1-1.2 (B), R22.1
unnamed: FM_L1-2.1 (A), R22.2
unnamed: FM_L1-2.2 (B), FM_L2-2.2 (B), FM_L3-2.2 (B), R28.2, R29.2, R31.1, U2.9 (-)
unnamed: FM_L2-1.2 (B), R23.1
unnamed: FM_L2-2.1 (A), R23.2
unnamed: FM_L3-1.2 (B), R24.1
unnamed: FM_L3-2.1 (A), R24.2
unnamed: C8.2, FM_R1-1.1 (A), FM_R2-1.1 (A), FM_R3-1.1 (A)
unnamed: FM_R1-1.2 (B), R19.1
unnamed: FM_R1-2.1 (A), R19.2
unnamed: FM_R1-2.2 (B), FM_R2-2.2 (B), FM_R3-2.2 (B), R26.2, R27.2, R30.1, U2.13 (-)
unnamed: FM_R2-1.2 (B), R20.1
unnamed: FM_R2-2.1 (A), R20.2
unnamed: FM_R3-1.2 (B), R21.1
unnamed: FM_R3-2.1 (A), R21.2
unnamed: LPF.1 (A), R32.2, U3.9 (BYPASS)
unnamed: M1PU.1 (A), R6.2, R9.2, R10.2
unnamed: PSG#2.1 (A), R8.1
unnamed: PSG#2.3 (B), R7.1
unnamed: R52.2, R53.1, U4.8
unnamed: C6.1, R3.1, U2.3 (+)
unnamed: C6.2, C8.1, U2.1, U2.2 (-)
unnamed: C7.1, R4.1, U2.5 (+)
unnamed: C7.2, C9.1, U2.6 (-), U2.7
unnamed: C10.2, U3.1 (CH1_IN)
unnamed: C11.2, U3.2 (CH2_IN)
unnamed: C12.2, U3.3 (CH3_IN)
unnamed: C13.2, U3.4 (CH4_IN)
unnamed: C30.1, R38.2, R39.2, R47.1, U4.2 (-)
unnamed: C31.1, R40.2, R41.2, R45.1, U4.6 (-)
unnamed: R48.2, R49.1, R52.1, U4.9 (-)
unnamed: C29.2, R43.2, U5.8 (BLUE)
unnamed: R55.1, U5.9 (CHROM_OUT)
unnamed: R56.1, U5.10 (CVBS_OUT)
unnamed: C28.2, R44.2, U5.7 (GREEN)
unnamed: R54.1, U5.11 (LUM_OUT)
unnamed: C27.2, R46.2, U5.6 (RED)
unnamed: C37.2, C38.1, U5.12 (TRAP)

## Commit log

2025-03-25 Added v0.2 (MegaAV)
    [MegaAV_rev0.2.kicad_pcb, MegaAV_rev0.2.kicad_sch]
2025-03-25 Silkscreen updated.
    [MegaAV_rev0.2.kicad_pcb]
2025-03-27 fixed silkscreening, minor trace rerouting, and added PCBA files. Note, these are not final.
    [BOM.csv, MegaAV_Saturn_rev0.2.kicad_pcb, MegaAV_rev0.2.kicad_pcb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]
2025-03-27 Added MegaAV logo
    [MegaAV_Saturn_rev0.2.kicad_pcb, MegaAV_rev0.2.kicad_pcb]
2025-07-09 Replace Mega AV Logo with current one
    [MegaAV_rev0.5.kicad_pcb]
2025-07-09 teardrops addee and removed some thermal reliefs on the zif conn
    [MegaAV_rev0.5.kicad_pcb]
2025-07-09 Schematic comments
2025-07-10 Added SL3 and SR3 (Sega CD passthrough)
    [MegaAV_rev0.5.kicad_pcb, MegaAV_rev0.5.kicad_sch]
2025-07-11 Silkscreen improvments
    [MegaAV_rev0.5.kicad_pcb]
2025-07-11 74HC86 support + silkscreening improvments.
    [MegaAV_rev0.5.kicad_pcb, MegaAV_rev0.5.kicad_sch, MegaAV_rev0.5_BOM.csv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]
2025-07-26 added 10k pullup to HCT123, silkscreening improvments, GND pad next to SBCR
    [MegaAV_rev0.5.kicad_pcb, MegaAV_rev0.5.kicad_sch]
2025-08-15 optimized luma trap values & PSG fix. Some silscreening to.
    [MegaAV_rev0.5.kicad_pcb, MegaAV_rev0.5.kicad_sch]
2025-08-20 36k 32x gain fix
    [MegaAV_rev0.5.kicad_sch]
2025-08-22 Fixed jumper silkscreening
    [MegaAV_rev0.5.kicad_pcb]
2025-10-30 Changes to the liscense, readme, and silkscreening.
    [BOM.csv, MegaAV_rev0.2.kicad_pcb, MegaAV_rev0.5.kicad_pcb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]
2025-10-30 Silkscreen change
    [MegaAV_VA1.kicad_pcb]
2025-11-13 Silkscreen fix
    [BOM.csv, MegaAV_VA1.kicad_pcb, MegaAV_VA1.kicad_sch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]
2025-11-21 MEGA AV Pro & CE revisions added
    [BOM.csv, BOM_VA2.csv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]
2025-11-21 folder name
    [BOM.csv, MegaAV_Pro_VA0.kicad_pcb, MegaAV_Pro_VA0.kicad_sch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]
2025-11-22 MegaAV VA0 CE PCBA updates
    [BOM_VA0.csv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]
2025-11-22 Fixed VA0 errors
    [BOM.csv, BOM_VA0.csv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]
